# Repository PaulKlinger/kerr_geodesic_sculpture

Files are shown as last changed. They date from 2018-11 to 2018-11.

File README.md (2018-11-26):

# 3D printed light sculpture showing the trajectory of a particle around a spinning black hole

(http://www.youtube.com/watch?v=DfhZvKPe3HQ "")

This shows a timeslice of the path of a massive particle (with some specific initial position and velocity that gives a nice looking trajectory) around a [spinning (Kerr) black hole](https://en.wikipedia.org/wiki/Kerr_metric) (with parameters m=1, a=1/3). The black (very slightly squashed) sphere in the center represents the event horizon of the black hole.

I calculated the trajectory using mathematica (code in the notebook.nb file)by directly integrating the [geodesic equations](https://en.wikipedia.org/wiki/Geodesics_in_general_relativity). [Here's](https://i.imgur.com/O50RE7Q.png) the piece of it in the sculpture, and [here's](https://i.imgur.com/HQwdpmr.png) a longer section. The particle will continue to orbit the black hole indefinitely, with the radius changing between a minimum and maximum value. In contrast to orbits around non-spinning black holes or stars/planets (which can only spin very slowly) the trajectory is three-dimensional, i.e. it doesn't just stay in one plane.

I imported the trajectory into Fusion 360, put a hollow tube around it, and [printed it](https://i.imgur.com/pHP71ye.jpg) on my Prusa Mk3. Then I pushed some [side glow fiber optic](https://www.aliexpress.com/item/5mX-Transparent-side-glow-plastic-PMMA-fiber-optic-cable-solid-core-optic-cable-diameter-2mm-3mm/32807597828.html) through the tube (that was the hardest part of the whole thing...). The base and black hole are also printed. In the base there is an attiny85 microcontroller, a potentiometer, and two WS2812b LEDs, powered via a micro usb socket. [Here's a picture](https://i.imgur.com/nm2dvyY.jpg) of the internals.

Twisting the black hole turns the potentiometer and changes the illumination between off, fixed color, color changing, and white.

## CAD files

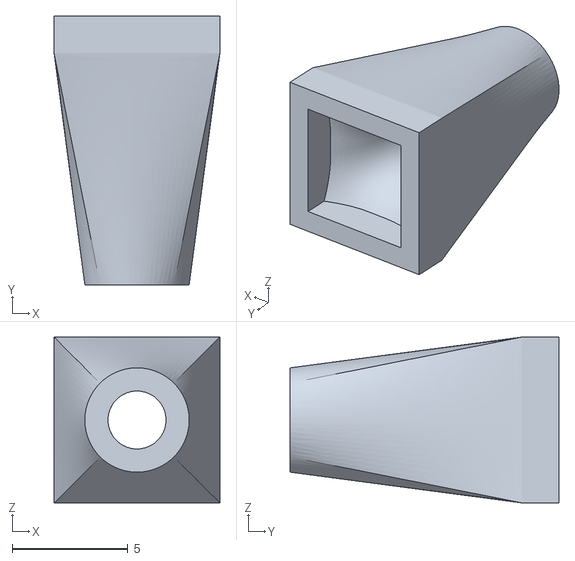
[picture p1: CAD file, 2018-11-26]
3d printed parts/coupling.stl
7.15 x 11.6 x 7.15

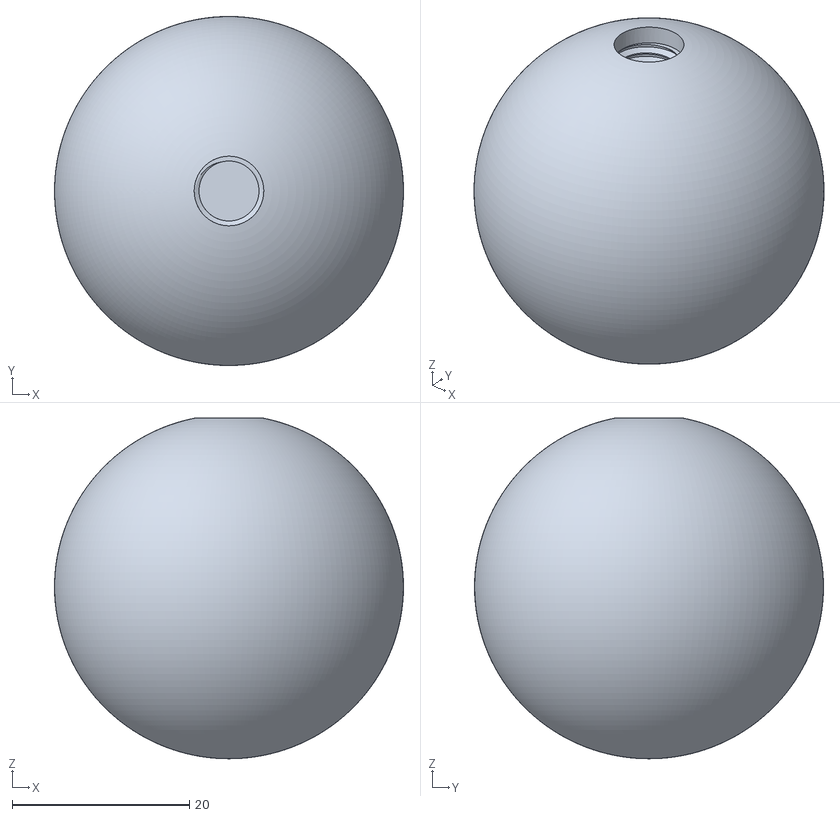
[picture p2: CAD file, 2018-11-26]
3d printed parts/black hole.stl
39.4 x 39.4 x 38.5

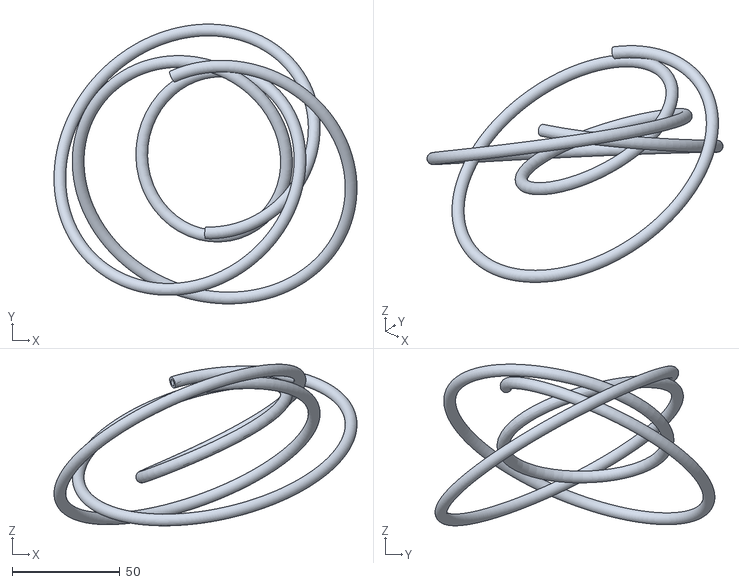
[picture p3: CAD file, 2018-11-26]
3d printed parts/geodesic_tube.stl
140.9 x 130.1 x 75.2

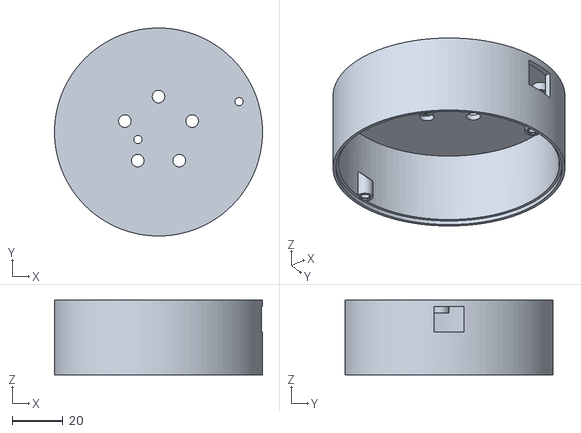
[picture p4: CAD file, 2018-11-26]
3d printed parts/body.stl
82.3 x 82.3 x 29.5

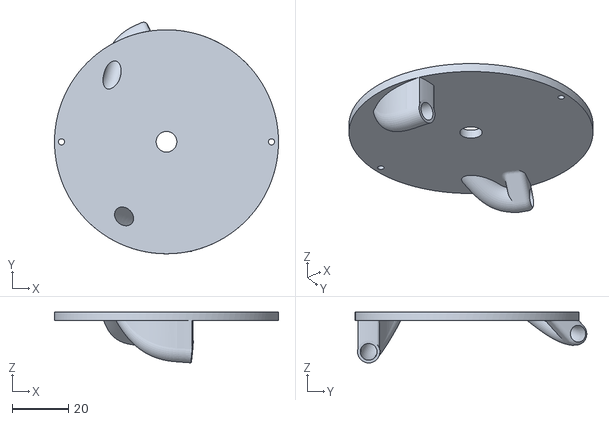
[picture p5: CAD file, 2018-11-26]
3d printed parts/base.stl
80.0 x 82.7 x 18.2

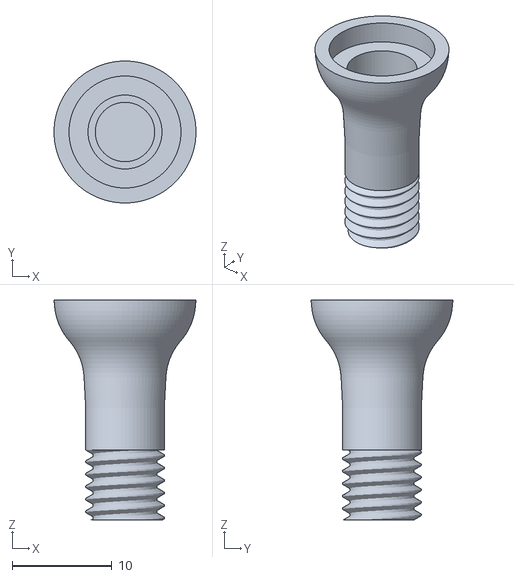
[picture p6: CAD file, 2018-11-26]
3d printed parts/bh_support.stl
14.2 x 14.2 x 22.0

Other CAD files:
3d printed parts/3d_printed_parts.f3d

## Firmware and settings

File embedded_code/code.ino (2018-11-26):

#include <Adafruit_NeoPixel.h>
#include <math.h>

#define PIN      2 // PB2 = Pin 7
#define N_LEDS 7
#define ANALOG_CHANNEL 3 // ADC3 = PB3 = Pin 2

Adafruit_NeoPixel strip = Adafruit_NeoPixel(N_LEDS, PIN, NEO_GRB + NEO_KHZ800);
uint8_t col2 = 0;

float h=0;
float s=1.0;
float l=0.5;
uint32_t color;
int analog_val;

void setup() {
  // put your setup code here, to run once:
  strip.begin();
  
}

void loop() {
  // put your main code here, to run repeatedly:

  analog_val = analogRead(ANALOG_CHANNEL);
  if (analog_val < 100) {
    color = strip.Color(0,0,0);
  } else if (analog_val < 800) {
    color = hsl_to_color((analog_val-100)/ 700.0f * 360.0f,s,l);
  } else if (analog_val < 900) {
    h += 0.05;
    if (h>=360) {
      h = 0;
    }
    color = hsl_to_color(h,s,l);
  } else {
    color = strip.Color(255,255,255);
  }
  strip.fill(color);
  strip.show();
  delay(10);
}

uint32_t hsl_to_color(float h, float s, float l) {
  // 0<=h<=360 0<=s<=1 0<=l<=1
  float c = (1.0- fabs(2.0*l-1.0))*s;
  float hp = h / 60.0;
  float x = c * (1.0 - fabs(fmod(hp, 2.0) - 1.0));
  float rl, gl, bl;
  if (0<= hp && hp<=1) {
    rl = c;
    gl = x;
    bl = 0;
  } else if (1 < hp && hp <= 2) {
    rl = x;
    gl = c;
    bl = 0;
  } else if (2< hp && hp <= 3) {
    rl = 0;
    gl = c;
    bl = x;
  } else if (3 < hp && hp <= 4) {
    rl = 0;
    gl = x;
    bl = c;
  } else if (4 < hp && hp <=5) {
    rl = x;
    gl = 0;
    bl = c;
  } else {
    rl = c;
    gl = 0;
    bl = x;
  }
  float m = l - c/2.0;
  return strip.Color((uint8_t)((rl + m) * 255), (uint8_t) ((gl + m) * 255), (uint8_t) ((bl + m) * 255));
}
